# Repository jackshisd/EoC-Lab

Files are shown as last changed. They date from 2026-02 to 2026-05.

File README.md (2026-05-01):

| Supported Targets | ESP32 | ESP32-P4 | ESP32-S3 |
| --- | ----- | --- | --- |

# ESP32-S3 SD + Mic + OV2640 Recorder

__WARNING:__ This project writes audio/video files to the SD card. Back up your data before testing.

Records:
- **Audio**: WAV via I2S mic (ICS-43434), `mic_0001.wav`, `mic_0002.wav`, ...
- **Contact audio**: WAV via ES8388 contact mic board, `CT0001.WAV`, `CT0002.WAV`, ...
- **Video**: MJPEG via OV2640, `VID0001.MJP`, `VID0002.MJP`, ...

Core features:
- SDMMC FAT mount/unmount
- USB MSC to expose the SD card when idle
- SSD1306 I2C OLED status
- Button UI
- BLE scan trigger (advertisements) with timestamped filenames
- Simultaneous standard mic + contact mic recording to separate WAV files
- Boot-time ES8388 codec bring-up so contact recording does not reinitialize the codec on every session

Supports SD (SDSC, SDHC, SDXC) cards and eMMC.

## Quick wiring map (ESP32-S3)

- **SD card (SDMMC):**
  - CLK: GPIO6
  - CMD: GPIO7
  - D0: GPIO5
  - D1: GPIO4
  - D2: GPIO16
  - D3: GPIO15
- **Mic (I2S):**
  - BCLK: GPIO38
  - LRCK/WS: GPIO40
  - DOUT -> ESP DIN: GPIO39
- **OLED (I2C, addr `0x3C`):**
  - SDA: GPIO1
  - SCL: GPIO2
- **Contact mic codec board (ES8388 + MCP6002):**
  - I2C SDA: GPIO1
  - I2C SCL: GPIO2
  - MCLK: GPIO41
  - ASDOUT -> ESP DIN: GPIO42
  - SCLK/BCLK: GPIO43
  - LRCK/WS: GPIO44
- **Button:**
  - GPIO45
- **Camera (OV2640):**
  - SCCB SDA: GPIO18
  - SCCB SCL: GPIO17
  - XCLK: GPIO9 (10 MHz)
  - D0..D7: GPIO47, GPIO48, GPIO14, GPIO21, GPIO12, GPIO13, GPIO10, GPIO11
  - PCLK: GPIO46
  - VSYNC: GPIO3
  - HREF: GPIO8
  - PWDN/RESET: tied in hardware (disabled in software with `-1`)

## Hardware

This project targets ESP32-S3 and uses an SD card breakout or slot, an I2S mic, an SSD1306 OLED, and an OV2640 camera.

Although it is possible to connect an SD card breakout adapter, keep in mind that connections using breakout cables are often unreliable and have poor signal integrity. You may need to use lower clock frequency when working with SD card breakout adapters.

This project doesn't utilize card detect (CD) and write protect (WP) signals from SD card slot.

### Pin assignments for ESP32

On ESP32, SDMMC peripheral is connected to specific GPIO pins using the IO MUX. GPIO pins cannot be customized. Please see the table below for the pin connections.

When using an ESP-WROVER-KIT board, this example runs without any extra modifications required. Only an SD card needs to be inserted into the slot.

ESP32 pin     | SD card pin | Notes
--------------|-------------|------------
GPIO14 (MTMS) | CLK         | 10k pullup in SD mode
GPIO15 (MTDO) | CMD         | 10k pullup in SD mode
GPIO2         | D0          | 10k pullup in SD mode, pull low to go into download mode (see Note about GPIO2 below!)
GPIO4         | D1          | not used in 1-line SD mode; 10k pullup in 4-line SD mode
GPIO12 (MTDI) | D2          | not used in 1-line SD mode; 10k pullup in 4-line SD mode (see Note about GPIO12 below!)
GPIO13 (MTCK) | D3          | not used in 1-line SD mode, but card's D3 pin must have a 10k pullup

### Pin assignments for ESP32-S3 (current project)

On ESP32-S3, SDMMC peripheral is connected to GPIO pins using GPIO matrix. This allows arbitrary GPIOs to be used to connect an SD card. In this example, GPIOs can be configured in two ways:

1. Using menuconfig: Run `idf.py menuconfig` in the project directory and open "SD/MMC Example Configuration" menu.
2. In the source code: See the initialization of `sdmmc_slot_config_t slot_config` structure in the example code.

The table below lists the default pin assignments.

When using an ESP32-S3-USB-OTG board, this example runs without any extra modifications required. Only an SD card needs to be inserted into the slot.

ESP32-S3 pin  | SD card pin | Notes
--------------|-------------|------------
GPIO6         | CLK         | 10k pullup
GPIO7         | CMD         | 10k pullup
GPIO5         | D0          | 10k pullup
GPIO4         | D1          | 10k pullup
GPIO16        | D2          | 10k pullup
GPIO15        | D3          | 10k pullup (required even in 1-line mode)

### I2S mic (ICS-43434)

ESP32-S3 pin  | Mic pin
--------------|---------
GPIO38        | BCLK/SCK
GPIO40        | WS/LRCL
GPIO39        | DOUT/SD
3.3V          | VCC
GND           | GND

SEL/LR on the mic should be tied to 3.3V (right channel), which matches the code.

### OLED (SSD1306, I2C)

ESP32-S3 pin  | OLED pin
--------------|---------
GPIO1         | SDA
GPIO2         | SCL
3.3V          | VCC
GND           | GND

I2C address is `0x3C`.

### Contact mic codec board (ES8388)

ESP32-S3 pin  | Contact mic board pin
--------------|----------------------
GPIO1         | CDATA / I2C SDA
GPIO2         | CCLK / I2C SCL
GPIO41        | MCLK
GPIO42        | ASDOUT / codec data out
GPIO43        | SCLK / BCLK
GPIO44        | LRCK / WS
3.3V          | Codec supply
GND           | GND

Current firmware behavior:

- The ES8388 codec is initialized once at boot.
- If codec init is slow, the OLED shows retry/progress messages during boot.
- Once the OLED shows `codec ok`, normal operation begins.
- Later recordings reuse the initialized codec instead of re-running full codec init every time.

### Camera (OV2640, Waveshare) — read this first

This project uses OV2640 over SCCB (I2C). The camera is sensitive to pin choice and initial frames are often corrupted.

**Current working pin map (ESP32-S3 custom board):**

ESP32-S3 pin | OV2640 pin | Notes
-------------|------------|------
GPIO18       | SCCB SDA   | Camera I2C data
GPIO17       | SCCB SCL   | Camera I2C clock
GPIO9        | XCLK       | External clock (10 MHz)
GPIO47       | D0         | Data bit 0
GPIO48       | D1         | Data bit 1
GPIO14       | D2         | Data bit 2
GPIO21       | D3         | Data bit 3
GPIO12       | D4         | Data bit 4
GPIO13       | D5         | Data bit 5
GPIO10       | D6         | Data bit 6
GPIO11       | D7         | Data bit 7
GPIO46       | PCLK       | Pixel clock
GPIO3        | VSYNC      | Frame sync
GPIO8        | HREF       | Line sync

PWDN and RESET are tied in hardware (PWDN -> GND, RESET -> 3.3V). In software, they are disabled (set to `-1`).

**What was broken and how it was fixed:**

- Camera capture initially failed because of a real solder bridge between `VSYNC` and `PCLK`.
  Fix: remove the bridge; camera now initializes and produces frames.
- OLED instability was partly caused by a pin conflict: OLED `SCL` and the buzzer both used GPIO2.
  Fix: remove all buzzer code so GPIO2 is dedicated to OLED `SCL`.
- Mic audio was silent with one mic connected because the code was reading the wrong I2S slot.
  Fix: switch the mic capture to the right channel and wire the mic `SEL/LR` pin high.
- FATFS without LFN rejects long filenames.
  Fix: keep video filenames 8.3-safe as `VID0001.MJP` and BLE timestamped names as `MMDDHHMM.MJP` / `MMDDHHMM.WAV`.

**Playback note:** `VIDxxxx.MJP` is a raw MJPEG stream (not a container). VLC can play it; for QuickTime, convert to AVI/MP4.

**Current camera behavior:**

- Video recording is capped in software at `10 FPS` to reduce camera/SD load and improve stability.

### BLE trigger and timestamped filenames

The device scans BLE advertisements and uses a UUID-encoded timestamp to name files:

- **Video:** `MMDDHHMM.MJP`
- **Audio:** `MMDDHHMM.WAV`
- **Contact audio:** a contact-mic WAV derived from the same BLE timestamp, with the first timestamp character replaced by `C` to stay 8.3-safe

If no valid BLE timestamp is seen, it falls back to the index names:

- `VID0001.MJP`
- `mic_0001.wav`
- `CT0001.WAV`

**UUID format (128-bit):** `00000000-0000-0000-TT00-YYMMDDHHMMSS`

- Prefix is fixed: all zeroes (`00 00 00 00 00 00 00 00`)
- `TT` = `01` short press, `02` long press
- `YYMMDDHHMMSS` are BCD digits (base-10 nibbles)
- Filenames use `MMDDHHMM` to stay 8.3-safe

**Current BLE scan behavior:**

- BLE trigger scanning is enabled.
- Scanning is passive with duplicate filtering disabled.
- Scan duty cycle was reduced from continuous `10 ms / 10 ms` (~100%) to `5 ms / 80 ms` (~6.25%) to reduce radio and power load while keeping start/stop trigger support during recording.

### Button

ESP32-S3 pin  | Device
--------------|---------
GPIO45        | Button (pull-up input)

### Pin assignments for ESP32-P4

On ESP32-P4, Slot 1 of the SDMMC peripheral is connected to GPIO pins using GPIO matrix. This allows arbitrary GPIOs to be used to connect an SD card. In this example, GPIOs can be configured in two ways:

1. Using menuconfig: Run `idf.py menuconfig` in the project directory and open `SD/MMC Example Configuration` menu.
2. In the source code: See the initialization of `sdmmc_slot_config_t slot_config` structure in the example code.

The table below lists the default pin assignments.

ESP32-P4 pin  | SD card pin | Notes
--------------|-------------|------------
GPIO43        | CLK         | 10k pullup
GPIO44        | CMD         | 10k pullup
GPIO39        | D0          | 10k pullup
GPIO40        | D1          | not used in 1-line SD mode; 10k pullup in 4-line mode
GPIO41        | D2          | not used in 1-line SD mode; 10k pullup in 4-line mode
GPIO42        | D3          | not used in 1-line SD mode, but card's D3 pin must have a 10k pullup

Default dedicated pins on ESP32-P4 are able to connect to an ultra high-speed SD card (UHS-I) which requires 1.8V switching (instead of the regular 3.3V). This means the user has to provide an external LDO power supply to use them, or to enable and configure an internal LDO via `idf.py menuconfig` -> `SD/MMC Example Configuration` -> `SD power supply comes from internal LDO IO`.

When using different GPIO pins this is not required and `SD power supply comes from internal LDO IO` setting can be disabled.

### 4-line and 1-line SD modes

By default, this example uses 4 line SD mode, utilizing 6 pins: CLK, CMD, D0 - D3. It is possible to use 1-line mode (CLK, CMD, D0) by changing "SD/MMC bus width" in the example configuration menu (see `CONFIG_EXAMPLE_SDMMC_BUS_WIDTH_1`).

Note that even if card's D3 line is not connected to the ESP chip, it still has to be pulled up, otherwise the card will go into SPI protocol mode.

### Note about GPIO2 (ESP32 only)

GPIO2 pin is used as a bootstrapping pin, and should be low to enter UART download mode. One way to do this is to connect GPIO0 and GPIO2 using a jumper, and then the auto-reset circuit on most development boards will pull GPIO2 low along with GPIO0, when entering download mode.

- Some boards have pulldown and/or LED on GPIO2. LED is usually ok, but pulldown will interfere with D0 signals and must be removed. Check the schematic of your development board for anything connected to GPIO2.

### Note about GPIO12 (ESP32 only)

GPIO12 is used as a bootstrapping pin to select output voltage of an internal regulator which powers the flash chip (VDD_SDIO). This pin has an internal pulldown so if left unconnected it will read low at reset (selecting default 3.3V operation). When adding a pullup to this pin for SD card operation, consider the following:

- For boards which don't use the internal regulator (VDD_SDIO) to power the flash, GPIO12 can be pulled high.
- For boards which use 1.8V flash chip, GPIO12 needs to be pulled high at reset. This is fully compatible with SD card operation.
- On boards which use the internal regulator and a 3.3V flash chip, GPIO12 must be low at reset. This is incompatible with SD card operation.
    * In most cases, external pullup can be omitted and an internal pullup can be enabled using a `gpio_pullup_en(GPIO_NUM_12);` call. Most SD cards work fine when an internal pullup on GPIO12 line is enabled. Note that if ESP32 experiences a power-on reset while the SD card is sending data, high level on GPIO12 can be latched into the bootstrapping register, and ESP32 will enter a boot loop until external reset with correct GPIO12 level is applied.
    * Another option is to burn the flash voltage selection efuses. This will permanently select 3.3V output voltage for the internal regulator, and GPIO12 will not be used as a bootstrapping pin. Then it is safe to connect a pullup resistor to GPIO12. This option is suggested for production use.

The following command can be used to program flash voltage selection efuses **to 3.3V**:

```sh
    espefuse.py set_flash_voltage 3.3V
```

This command will burn the `XPD_SDIO_TIEH`, `XPD_SDIO_FORCE`, and `XPD_SDIO_REG` efuses. With all three burned to value 1, the internal VDD_SDIO flash voltage regulator is permanently enabled at 3.3V. See the technical reference manual for more details.

`espefuse.py` has a `--do-not-confirm` option if running from an automated flashing script.

See [the document about pullup requirements](https://docs.espressif.com/projects/esp-idf/en/latest/api-reference/peripherals/sd_pullup_requirements.html) for more details about pullup support and compatibility of modules and development boards.

## How to use

### Build and flash

Build the project and flash it to the board, then run monitor tool to view serial output:

```
idf.py -p PORT flash monitor
```

(Replace PORT with serial port name.)

(To exit the serial monitor, type ``Ctrl-]``.)

### Recording flow

1. Long press starts recording. USB MSC is stopped and the SD card is mounted to the app.
2. The normal I2S mic and the ES8388 contact mic are both recorded at the same time into separate WAV files.
3. Video is recorded in parallel if the camera is enabled and initialized.
4. Long press again stops recording, finalizes the WAV header(s), waits for the camera task to stop, and returns the SD card to USB MSC.
5. A later long press repeats the cycle with a new filename set.

### Idle / post-record OLED messages

The OLED status is more specific than a generic `Ready` screen:

- Clean success: `Recorded Xs at` + the standard mic filename
- Standard mic file exists even if the task reported a higher-level failure: `Mic file saved`
- Standard mic saved but contact mic failed: `Mic saved; c fail`
- Startup codec bring-up: retry/progress messages followed by `codec ok`

Short press toggles pause/resume during recording.

### SD card mount warnings

If SD mounting fails or is not ready, the OLED shows a warning:

- `SD init failed`
- `SD mount failed`
- `SD not ready`

When these appear, re-seat the SD card and try again. Also wait for the
`Exposing SD card over USB` log before unplugging or copying files.

See the Getting Started Guide for full steps to configure and use ESP-IDF to build projects.

### USB mass storage

When idle, the SD card is exposed over USB MSC for file access from your computer.
During recording, USB MSC is stopped and the SD card is mounted to the application.
After recording finishes, USB MSC is restarted and the card is visible again on the host.

## Example output

Here is an example console output. In this case a 128MB SDSC card was connected, and `EXAMPLE_FORMAT_IF_MOUNT_FAILED` menuconfig option enabled. Card was unformatted, so the initial mount has failed. Card was then partitioned, formatted, and mounted again.

```
I (336) example: Initializing SD card
I (336) example: Using SDMMC peripheral
I (420) example: Mounting filesystem
I (538) mic: Waiting for long press
I (1840) button: Recording started
I (1841) mic: Recording started
I (9620) mic: Stop requested
I (9622) mic: Captured 7 sec to /sdcard/mic_0001.wav
I (9660) example: Card unmounted
```

## Troubleshooting

### Failure to download the example

```
Connecting........_____....._____....._____....._____....._____....._____....._____

A fatal error occurred: Failed to connect to Espressif device: Invalid head of packet (0x34)
```

Disconnect the SD card D0/MISO line from GPIO2 and try uploading again. Read "Note about GPIO2" above.

### Card fails to initialize with `sdmmc_init_sd_scr: send_scr (1) returned 0x107` error

Check connections between the card and the ESP32. For example, if you have disconnected GPIO2 to work around the flashing issue, connect it back and reset the ESP32 (using a button on the development board, or by pressing Ctrl-T Ctrl-R in IDF Monitor).

### Card fails to initialize with `sdmmc_check_scr: send_scr returned 0xffffffff` error

Connections between the card and the ESP32 are too long for the frequency used. Try using shorter connections, or try reducing the clock speed of SD interface.

### Failure to mount filesystem

```
example: Failed to mount filesystem. If you want the card to be formatted, set the EXAMPLE_FORMAT_IF_MOUNT_FAILED menuconfig option.
```
The example will be able to mount only cards formatted using FAT32 filesystem. If the card is formatted as exFAT or some other filesystem, you have an option to format it in the example code. Enable the `EXAMPLE_FORMAT_IF_MOUNT_FAILED` menuconfig option, then build and flash the example.

### Debug SD connections and pullup strength

> If the initialization of the SD card fails, initially follow the above options. If the issue persists, confirm the connection of pullups to the SD pins. To do this, enable the` Debug sd pin connections and pullup strength` option from menuconfig and rerun the code. This will provide the following result:

```
**** PIN recovery time ****

PIN 14 CLK  10044 cycles
PIN 15 CMD  10034 cycles
PIN  2  D0  10034 cycles
PIN  4  D1  10034 cycles
PIN 12  D2  10034 cycles
PIN 13  D3  10034 cycles

**** PIN recovery time with weak pullup ****

PIN 14 CLK  100 cycles
PIN 15 CMD  100 cycles
PIN  2  D0  100 cycles
PIN  4  D1  100 cycles
PIN 12  D2  100 cycles
PIN 13  D3  100 cycles

**** PIN voltage levels ****

PIN 14 CLK  0.6V
PIN 15 CMD  0.3V
PIN  2  D0  0.8V
PIN  4  D1  0.6V
PIN 12  D2  0.4V
PIN 13  D3  0.8V

**** PIN voltage levels with weak pullup ****

PIN 14 CLK  1.0V
PIN 15 CMD  1.1V
PIN  2  D0  1.0V
PIN  4  D1  1.0V
PIN 12  D2  1.0V
PIN 13  D3  1.2V

**** PIN cross-talk ****

              CLK   CMD    D0    D1    D2    D3
PIN 14 CLK     --   0.2V  0.1V  0.1V  0.1V  0.2V
PIN 15 CMD    0.1V   --   0.1V  0.1V  0.1V  0.1V
PIN  2  D0    0.1V  0.1V   --   0.2V  0.1V  0.1V
PIN  4  D1    0.1V  0.1V  0.3V   --   0.1V  0.1V
PIN 12  D2    0.1V  0.2V  0.2V  0.1V   --   0.1V
PIN 13  D3    0.1V  0.2V  0.1V  0.1V  0.1V   --

**** PIN cross-talk with weak pullup ****

              CLK   CMD    D0    D1    D2    D3
PIN 14 CLK     --   1.0V  1.0V  1.0V  1.0V  1.2V
PIN 15 CMD    0.9V   --   1.0V  1.0V  1.0V  1.2V
PIN  2  D0    0.9V  1.0V   --   1.0V  1.0V  1.2V
PIN  4  D1    0.9V  1.0V  1.2V   --   1.0V  1.2V
PIN 12  D2    0.9V  1.1V  1.2V  0.9V   --   1.2V
PIN 13  D3    0.9V  1.2V  1.1V  0.9V  0.9V   --
I (845) main_task: Returned from app_main()
```

In the absence of connected pullups and having the weak pullups enabled, you can assess the pullup connections by comparing PIN recovery time measured in CPU cycles. To check pullup connections, configure the pin as open drain, set it to low state, and count the cpu cycles consumed before returning to high state. If a pullup is connected, the pin will get back to high state after reasonably small cycle count, typically around 50-300 cycles, depending on pullup strength. If no pullup is connected, the PIN stays low and the measurement times out after 10000 cycles.

It will also provide the voltage levels at the corresponding SD pins. By default, this information is provided for ESP32 chip only, and for other chipsets, verify the availability of ADC pins for the respective GPIO using [this](https://docs.espressif.com/projects/esp-idf/en/latest/esp32/api-reference/peripherals/gpio.html#gpio-summary) and configure ADC mapped pins using menuconfig. Then test the voltage levels accordingly.

You can monitor the voltage levels of individual pins using `PIN voltage levels` and `PIN voltage levels with weak pullup`. However, if one pin being pulled low and experiencing interference with another pin, you can detect it through `PIN cross-talk` and `PIN cross-talk with weak pullup`. In the absence of pullups, voltage levels at each pin should range from 0 to 0.3V. With 10k pullups connected, the voltage will be between 3.1V to 3.3V, contingent on the connection between ADC pins and SD pins, and with weak pullups connected, it can fluctuate between 0.8V to 1.2V, depending on pullup strength.
>>>>>>> 207d2c1 (Initial commit)

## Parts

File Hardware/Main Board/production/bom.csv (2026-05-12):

Designator | Footprint | Quantity | Value | LCSC Part #
1V2, A2V8, BATT1, TP6, TP7, TP9, VIN1 | TestPoint_Pad_1.0x1.0mm | 7 | TestPoint
3V3, GND1, TP3 | PinHeader_1x01_P2.54mm_Vertical | 3 | TestPoint
600Ω@100MHZ1 | 0603 | 1 | FerriteBead
BOOT1, RESET1, USER_INPUT1 | SW_SPST_TL3342 | 3 | SW_Push
BT1 | JST_PH_S2B-PH-K_1x02_P2.00mm_Horizontal | 1 | Battery_Cell
C1, C3, C8 | 0402 | 3 | 0.1uF
C10, C2, C7 | 0402 | 3 | 10uF
C11, C12, C13 | 0805 | 3 | 22uF
C14, C15, C16, C17 | 0603 | 4 | 0.1uF
C18, C19, C20, C21 | 0603 | 4 | 1uF
C4, C5, C6 | 0603 | 3 | 10uF
C9 | 0402 | 1 | 10pF
CAM1 | OV2640 | 1 | OV2640
D1 | PinHeader_1x02_P2.54mm_Vertical | 1 | LED
D2, D3 | 0603 | 2 | LED
D5 | D_SMA | 1 | SS14
F1 | 1206 | 1 | Fuse
J1 | microSD_HC_Molex_104031-0811 | 1 | Micro_SD_Card_Det1
J3 | JST_GH_SM09B-GHS-TB_1x09-1MP_P1.25mm_Horizontal | 1 | Conn_01x09_Socket
J4 | JST_GH_SM06B-GHS-TB_1x06-1MP_P1.25mm_Horizontal | 1 | MIC 1 Connector
J5 | JST_GH_SM06B-GHS-TB_1x06-1MP_P1.25mm_Horizontal | 1 | MIC 2 Connector
J6 | USB_C_Receptacle_HRO_TYPE-C-31-M-12 | 1 | USB_C_Receptacle_USB2.0_16P
J7 | PinHeader_1x04_P2.54mm_Vertical | 1 | OLED
L1 | L_Bourns-SRN4018 | 1 | 1uH
Q1 | SOT-23 | 1 | AO3401A
R1, R12, R13, R14 | 0402 | 4 | 10k
R10, R23, R28, R9 | 0402 | 4 | 22
R11, R17, R26 | 0402 | 3 | 4.7k
R15, R27 | 0402 | 2 | 0
R16 | 0402 | 1 | 560k
R18, R24 | 0402 | 2 | 100k
R19 | 0402 | 1 | 1M
R2, R3, R4, R5, R6, R7 | 0402 | 6 | 47k
R21, R22 | 0402 | 2 | 5.1k
SW1 | PinHeader_1x03_P2.54mm_Vertical | 1 | SW_SPST
U1 | ESP32-S3-WROOM-2 | 1 | ESP32-S3-WROOM-2
U2 | Texas_S-PWSON-N10_ThermalVias | 1 | TPS63060
U3 | SOIC-8-1EP_3.9x4.9mm_P1.27mm_EP2.41x3.3mm_ThermalVias | 1 | TP4056-42-ESOP8
U4 | SOT-23-5 | 1 | TLV75528PDBV
U6 | SOT-23-5 | 1 | AP2112K-1.2

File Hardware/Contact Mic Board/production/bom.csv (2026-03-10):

Designator | Footprint | Quantity | Value | LCSC Part #
C1, C16, C18, C19, C3, C5, C6 | 0402 | 7 | 0.1uF
C10, C13, C8, C9 | 0402 | 4 | 1uF
C11, C12 | 0402 | 2 | 470nF
C14, C15, C17, C2, C20, C4, C7 | 0402 | 7 | 10uF
FB1 | 0603 | 1 | FerriteBead_Small
J1 | JST_GH_SM09B-GHS-TB_1x09-1MP_P1.25mm_Horizontal | 1 | Conn_01x09_Pin
R1, R2 | 0402 | 2 | 47k
R10, R9 | 0402 | 2 | 1M
R11, R12, R13, R14 | 0402 | 4 | 33
R3, R4 | 0402 | 2 | 10M
R5, R6 | 0805 | 2 | 100k
R7, R8 | 0402 | 2 | 10K
U1 | QFN-28-1EP_4x4mm_P0.45mm_EP2.6x2.6mm | 1 | ES8388
U2 | DFN-8-1EP_3x2mm_P0.5mm_EP1.75x1.45mm | 1 | MCP6002-xMC

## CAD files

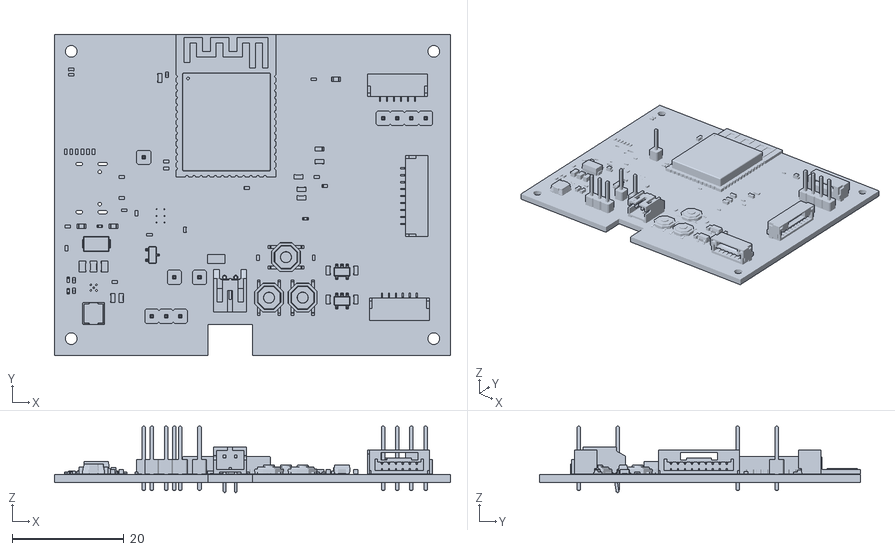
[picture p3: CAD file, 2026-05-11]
Hardware/Main Board/Main Board.stl
71.0 x 57.5 x 11.9

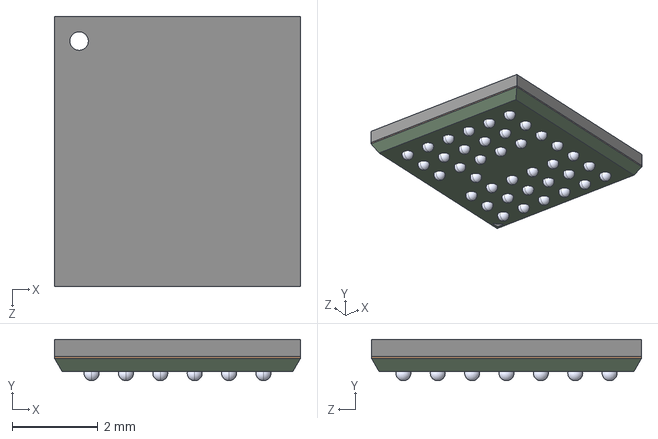
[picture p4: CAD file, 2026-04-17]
Hardware/Main Board/OV2640/OV2640.step
5.72 x 0.965 x 6.29 mm

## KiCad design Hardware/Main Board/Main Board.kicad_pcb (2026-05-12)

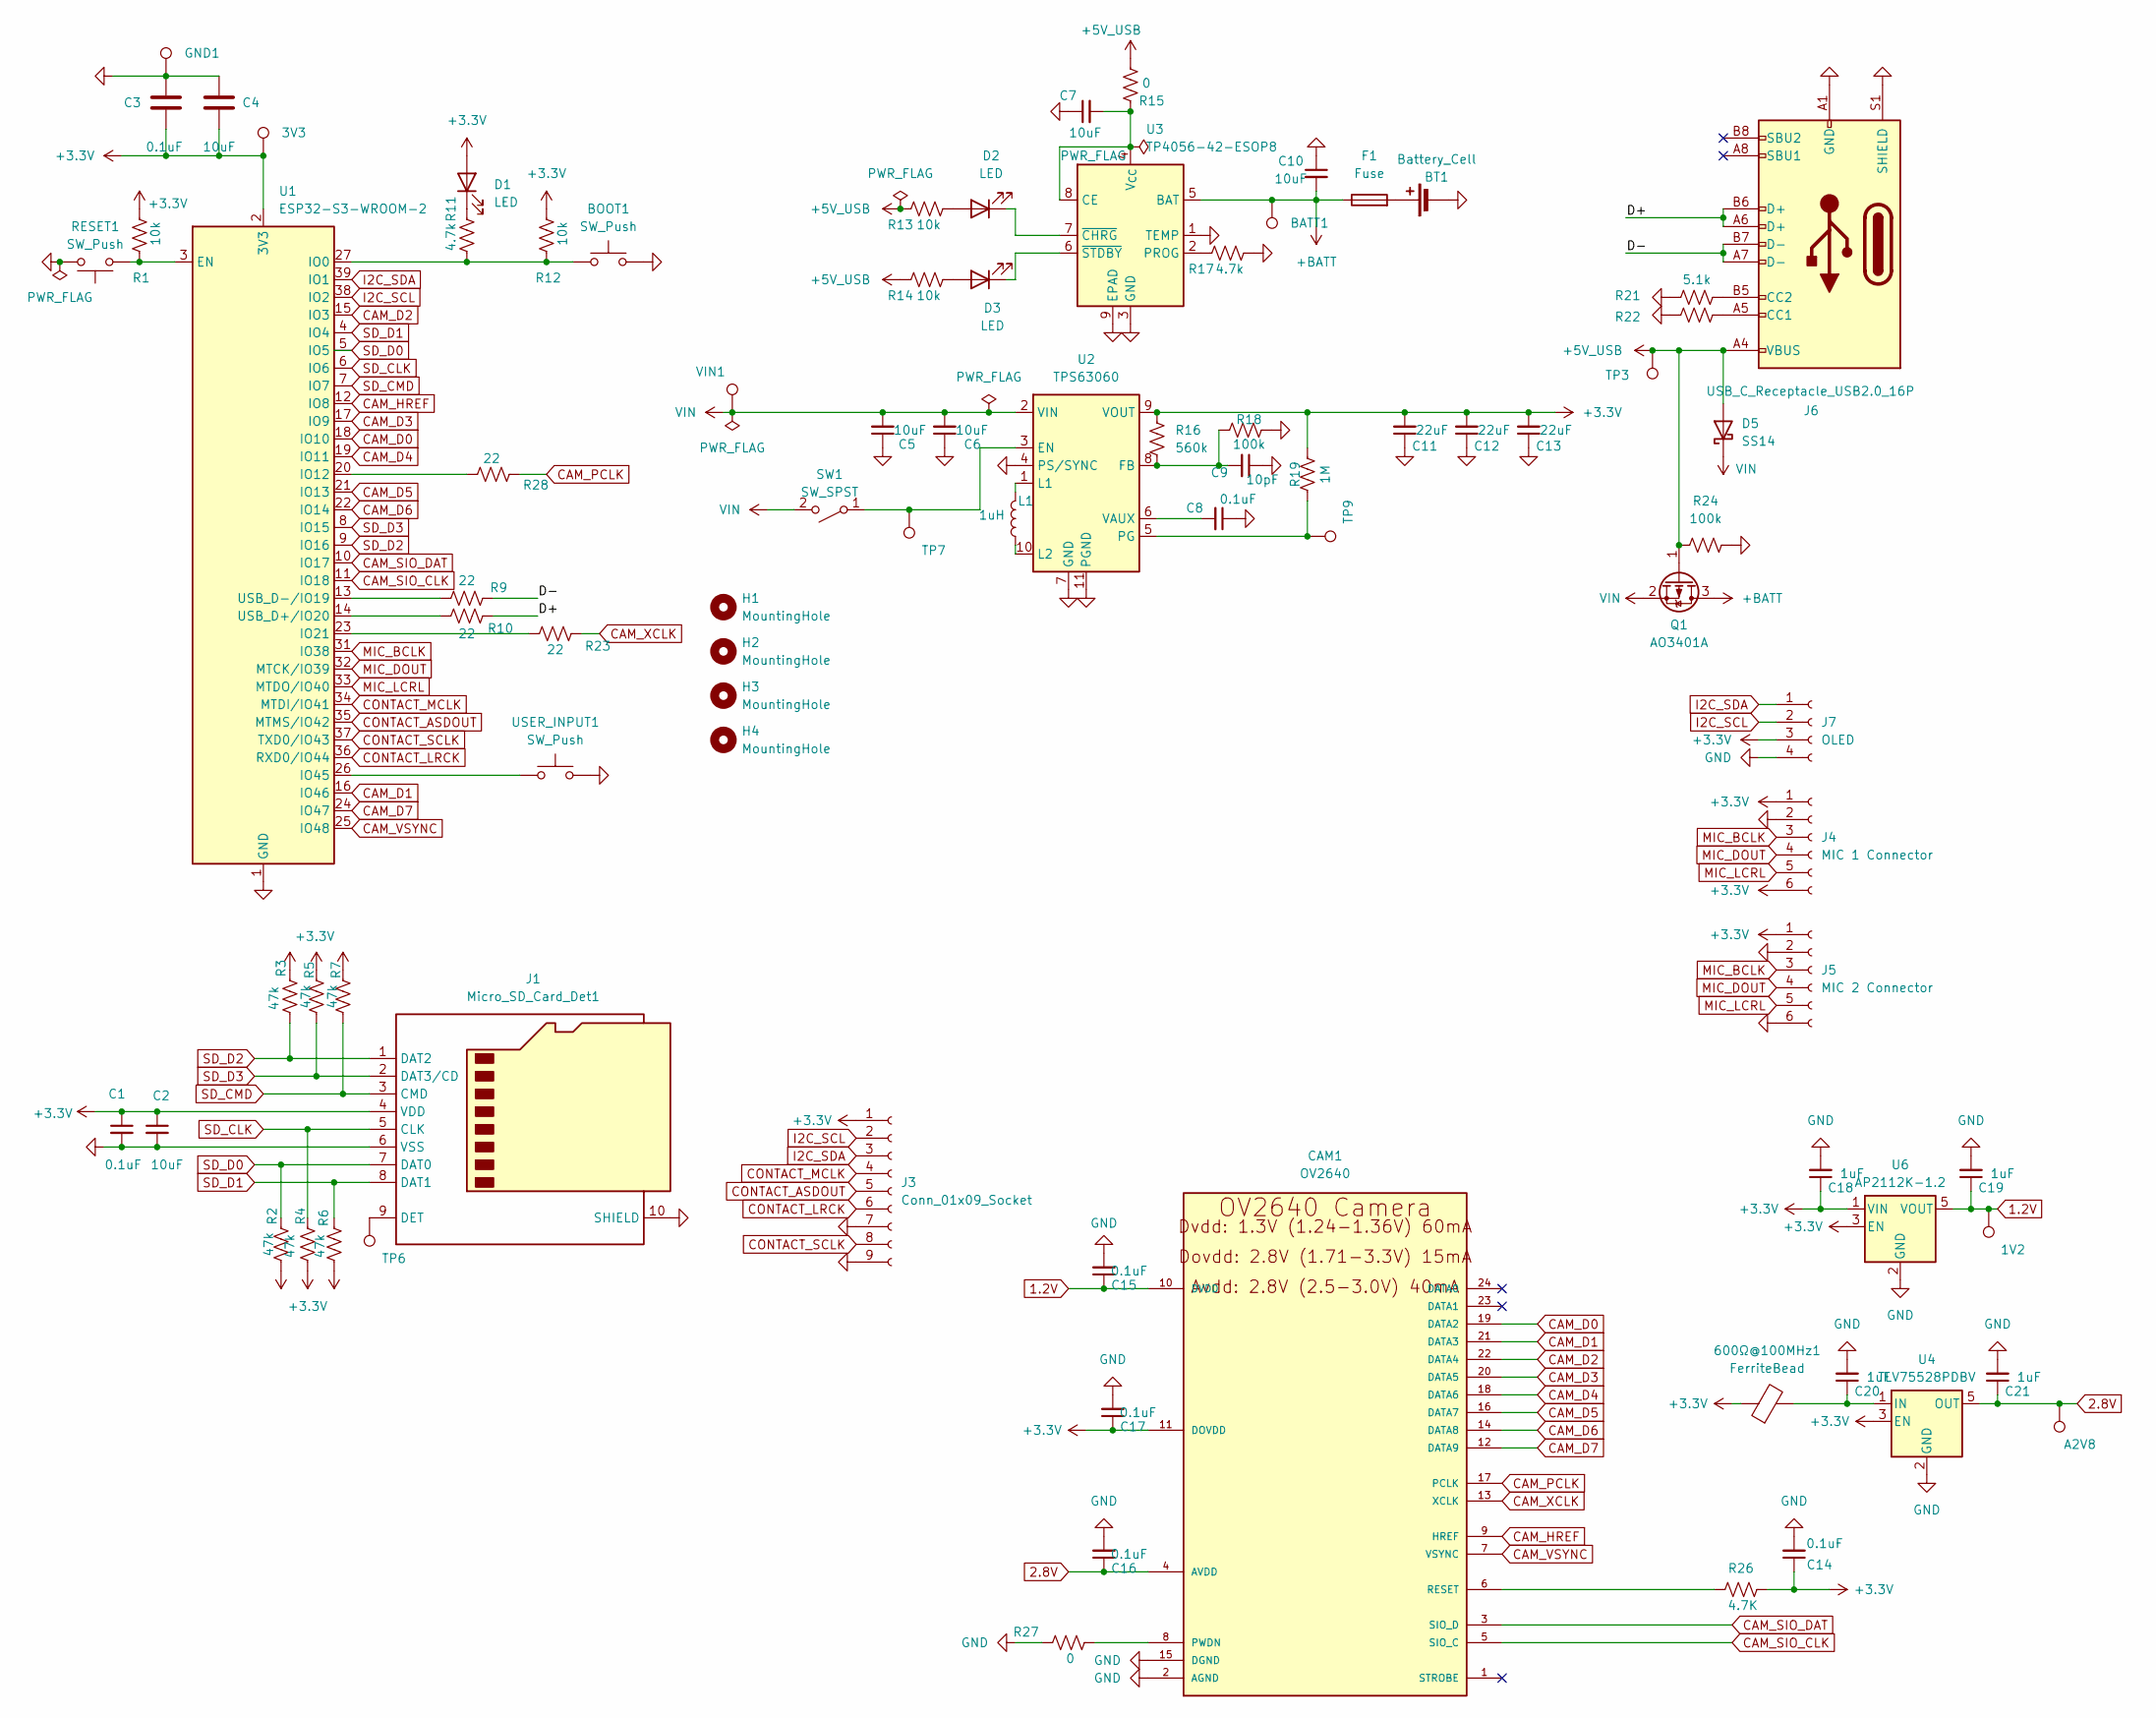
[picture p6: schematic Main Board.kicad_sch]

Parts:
1V2: TestPoint; TestPoint_Pad_1.0x1.0mm
3V3: TestPoint; PinHeader_1x01_P2.54mm_Vertical
600Ω@100MHz1: FerriteBead; R_0603_1608Metric
A2V8: TestPoint; TestPoint_Pad_1.0x1.0mm
BATT1: TestPoint; TestPoint_Pad_1.0x1.0mm
BOOT1: SW_Push; SW_SPST_TL3342
BT1: Battery_Cell; JST_PH_S2B-PH-K_1x02_P2.00mm_Horizontal
C1, C3, C8: 0.1uF; C_0402_1005Metric
C2, C7, C10: 10uF; C_0402_1005Metric
C4, C5, C6: 10uF; C_0603_1608Metric
C9: 10pF; C_0402_1005Metric
C11, C12, C13: 22uF; C_0805_2012Metric
C14, C15, C16, C17: 0.1uF; C_0603_1608Metric
C18, C19, C20, C21: 1uF; C_0603_1608Metric
CAM1: OV2640
D1: LED; PinHeader_1x02_P2.54mm_Vertical
D2, D3: LED; LED_0603_1608Metric
D5: SS14; D_SMA
F1: Fuse; Fuse_1206_3216Metric
GND1: TestPoint; PinHeader_1x01_P2.54mm_Vertical
H1, H2, H3, H4: MountingHole; MountingHole_2.1mm
J1: Micro_SD_Card_Det1; microSD_HC_Molex_104031-0811
J3: Conn_01x09_Socket; JST_GH_SM09B-GHS-TB_1x09-1MP_P1.25mm_Horizontal
J4: MIC 1 Connector; JST_GH_SM06B-GHS-TB_1x06-1MP_P1.25mm_Horizontal
J5: MIC 2 Connector; JST_GH_SM06B-GHS-TB_1x06-1MP_P1.25mm_Horizontal
J6: USB_C_Receptacle_USB2.0_16P; USB_C_Receptacle_HRO_TYPE-C-31-M-12
J7: OLED; PinHeader_1x04_P2.54mm_Vertical
L1: 1uH; L_Bourns-SRN4018
Q1: AO3401A; SOT-23
R1, R12, R13, R14: 10k; R_0402_1005Metric
R2, R3, R4, R5, R6, R7: 47k; R_0402_1005Metric
R9, R10, R23, R28: 22; R_0402_1005Metric
R11, R17: 4.7k; R_0402_1005Metric
R15, R27: 0; R_0402_1005Metric
R16: 560k; R_0402_1005Metric
R18, R24: 100k; R_0402_1005Metric
R19: 1M; R_0402_1005Metric
R21, R22: 5.1k; R_0402_1005Metric
R26: 4.7K; R_0402_1005Metric
RESET1: SW_Push; SW_SPST_TL3342
SW1: SW_SPST; PinHeader_1x03_P2.54mm_Vertical
TP3: TestPoint; PinHeader_1x01_P2.54mm_Vertical
TP6, TP7, TP9: TestPoint; TestPoint_Pad_1.0x1.0mm
U1: ESP32-S3-WROOM-2
U2: TPS63060; Texas_S-PWSON-N10_ThermalVias
U3: TP4056-42-ESOP8; SOIC-8-1EP_3.9x4.9mm_P1.27mm_EP2.41x3.3mm_ThermalVias
U4: TLV75528PDBV; SOT-23-5
U6: AP2112K-1.2; SOT-23-5
USER_INPUT1: SW_Push; SW_SPST_TL3342
VIN1: TestPoint; TestPoint_Pad_1.0x1.0mm

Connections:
1.2V: 1V2.1, C15.1, C19.1, CAM1.10 (DVDD), U6.5 (VOUT)
2.8V: A2V8.1, C16.1, C21.1, CAM1.4 (AVDD), U4.5 (OUT)
+3.3V: 3V3.1, 600Ω@100MHz1.1, C1.1, C2.1, C3.2, C4.1, C11.2, C12.2, C13.2, C14.1, C17.1, C18.1, CAM1.11 (DOVDD), D1.2 (A), J1.4 (VDD), J3.1, J4.1, J4.6, J5.1, J7.3, R1.1, R2.1, R3.2, R4.1, R5.2, R6.1, R7.2, R12.1, R16.2, R19.2, R26.1, U1.2 (3V3), U2.9 (VOUT), U4.3 (EN), U6.1 (VIN), U6.3 (EN)
+5V_USB: D5.2 (A), J6.A4 (VBUS), J6.A9 (VBUS), J6.B4 (VBUS), J6.B9 (VBUS), Q1.1 (G), R13.2, R14.2, R15.1, R24.1, TP3.1
+BATT: BATT1.1, C10.2, F1.1, Q1.3 (D), U3.5 (BAT)
/D+: J6.A6 (D+), J6.B6 (D+), R10.1
/D-: J6.A7 (D-), J6.B7 (D-), R9.1
CAM_D0: CAM1.19 (DATA2), U1.18 (IO10)
CAM_D1: CAM1.21 (DATA3), U1.16 (IO46)
CAM_D2: CAM1.22 (DATA4), U1.15 (IO3)
CAM_D3: CAM1.20 (DATA5), U1.17 (IO9)
CAM_D4: CAM1.18 (DATA6), U1.19 (IO11)
CAM_D5: CAM1.16 (DATA7), U1.21 (IO13)
CAM_D6: CAM1.14 (DATA8), U1.22 (IO14)
CAM_D7: CAM1.12 (DATA9), U1.24 (IO47)
CAM_HREF: CAM1.9 (HREF), U1.12 (IO8)
CAM_PCLK: CAM1.17 (PCLK), R28.2
CAM_SIO_CLK: CAM1.5 (SIO_C), U1.11 (IO18)
CAM_SIO_DAT: CAM1.3 (SIO_D), U1.10 (IO17)
CAM_VSYNC: CAM1.7 (VSYNC), U1.25 (IO48)
CAM_XCLK: CAM1.13 (XCLK), R23.2
CONTACT_ASDOUT: J3.5, U1.35 (MTMS/IO42)
CONTACT_LRCK: J3.6, U1.36 (RXD0/IO44)
CONTACT_MCLK: J3.4, U1.34 (MTDI/IO41)
CONTACT_SCLK: J3.8, U1.37 (TXD0/IO43)
GND: BOOT1.2, BT1.2 (-), C1.2, C2.2, C3.1, C4.2, C5.1, C6.1, C7.1, C8.1, C9.1, C10.1, C11.1, C12.1, C13.1, C14.2, C15.2, C16.2, C17.2, C18.2, C19.2, C20.2, C21.2, CAM1.2 (AGND), CAM1.15 (DGND), CAM1.MT1 (DGND), CAM1.MT2 (DGND), GND1.1, J1.6 (VSS), J1.10 (SHIELD), J3.7, J3.9, J4.2, J5.2, J5.6, J6.A1 (GND), J6.A12 (GND), J6.B1 (GND), J6.B12 (GND), J6.S1 (SHIELD), J7.4, R17.1, R18.1, R21.2, R22.2, R24.2, R27.2, RESET1.2, U1.1 (GND), U1.40 (GND), U1.41 (GND), U2.4 (PS/SYNC), U2.7 (GND), U2.11 (PGND), U3.1 (TEMP), U3.3 (GND), U3.9 (EPAD), U4.2 (GND), U6.2 (GND), USER_INPUT1.2
I2C_SCL: J3.2, J7.2, U1.38 (IO2)
I2C_SDA: J3.3, J7.1, U1.39 (IO1)
MIC_BCLK: J4.3, J5.3, U1.31 (IO38)
MIC_DOUT: J4.4, J5.4, U1.32 (MTCK/IO39)
MIC_LCRL: J4.5, J5.5, U1.33 (MTDO/IO40)
unnamed: BT1.1 (+), F1.2
unnamed: CAM1.8 (PWDN), R27.1
unnamed: CAM1.6 (RESET), R26.2
unnamed: D1.1 (K), R11.2
unnamed: D2.2 (A), R13.1
unnamed: D2.1 (K), U3.7 (~CHRG)
unnamed: D3.2 (A), R14.1
unnamed: D3.1 (K), U3.6 (~STDBY)
unnamed: J1.9 (DET), TP6.1
unnamed: J6.A5 (CC1), R22.1
unnamed: J6.B5 (CC2), R21.1
unnamed: SW1.1 (A), TP7.1, U2.3 (EN)
unnamed: R1.2, RESET1.1, U1.3 (EN)
unnamed: BOOT1.1, R11.1, R12.2, U1.27 (IO0)
unnamed: R28.1, U1.20 (IO12)
unnamed: R23.1, U1.23 (IO21)
unnamed: U1.26 (IO45), USER_INPUT1.1
unnamed: R10.2, U1.14 (USB_D+/IO20)
unnamed: R9.2, U1.13 (USB_D-/IO19)
unnamed: C9.2, R16.1, R18.2, U2.8 (FB)
unnamed: L1.2, U2.1 (L1)
unnamed: L1.1, U2.10 (L2)
unnamed: R19.1, TP9.1, U2.5 (PG)
unnamed: C8.2, U2.6 (VAUX)
unnamed: C7.2, R15.2, U3.4 (V_{CC}), U3.8 (CE)
unnamed: R17.2, U3.2 (PROG)
unnamed: 600Ω@100MHz1.2, C20.1, U4.1 (IN)
SD_CLK: J1.5 (CLK), R4.2, U1.6 (IO6)
SD_CMD: J1.3 (CMD), R7.1, U1.7 (IO7)
SD_D0: J1.7 (DAT0), R2.2, U1.5 (IO5)
SD_D1: J1.8 (DAT1), R6.2, U1.4 (IO4)
SD_D2: J1.1 (DAT2), R3.1, U1.9 (IO16)
SD_D3: J1.2 (DAT3/CD), R5.1, U1.8 (IO15)
VIN: C5.2, C6.2, D5.1 (K), Q1.2 (S), SW1.2 (B), U2.2 (VIN), VIN1.1

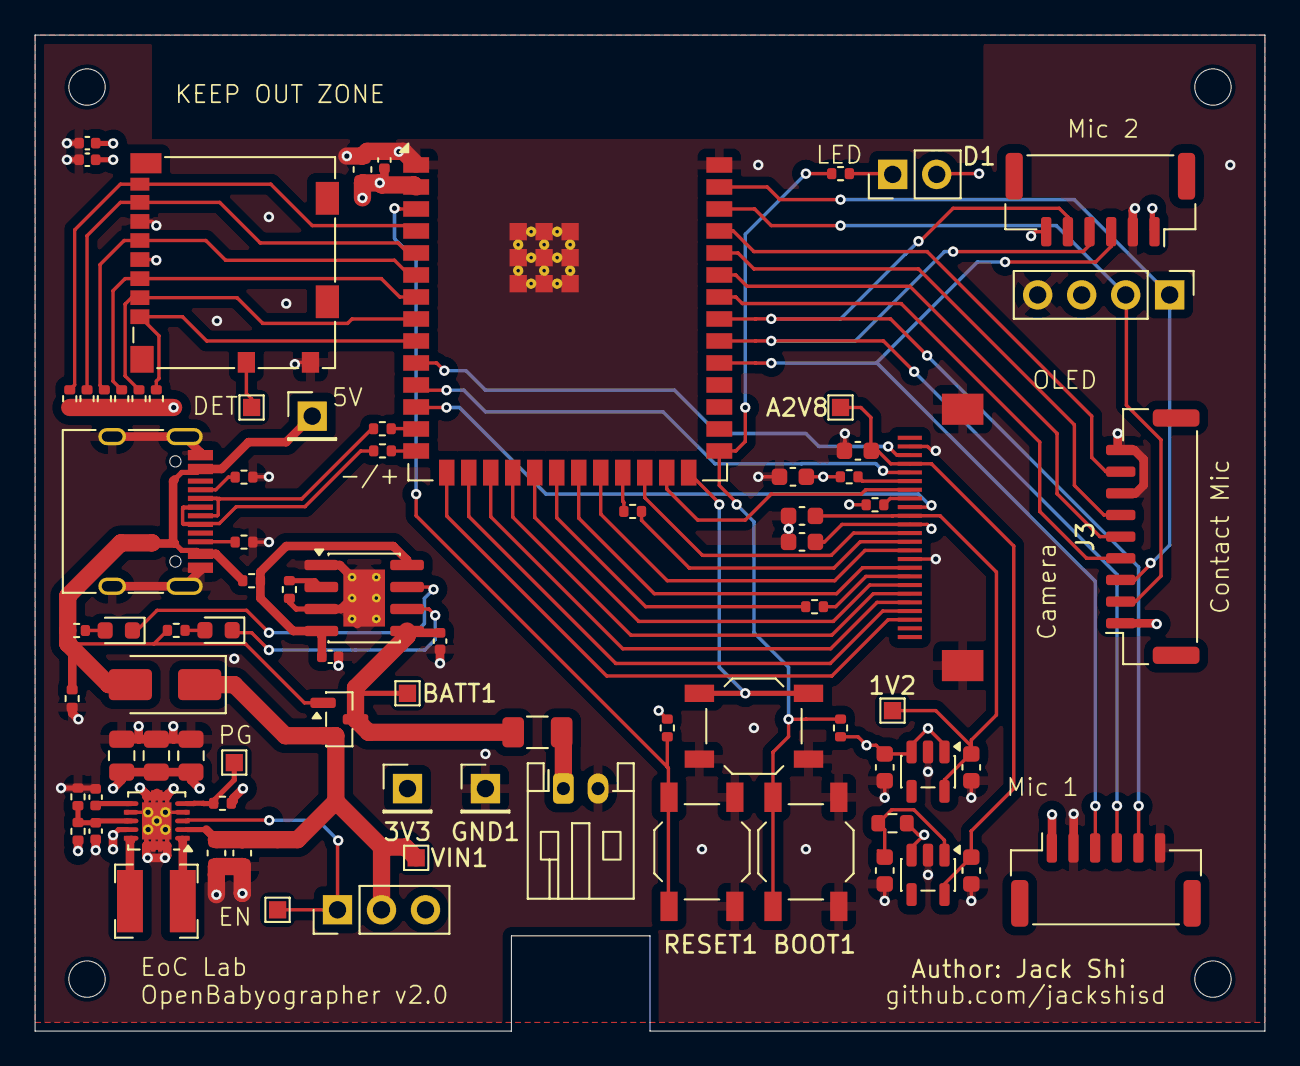
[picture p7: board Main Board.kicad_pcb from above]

Board: 4 copper layers, 71.0 x 57.5 mm, 85 parts (0 on the bottom side), 65 nets.

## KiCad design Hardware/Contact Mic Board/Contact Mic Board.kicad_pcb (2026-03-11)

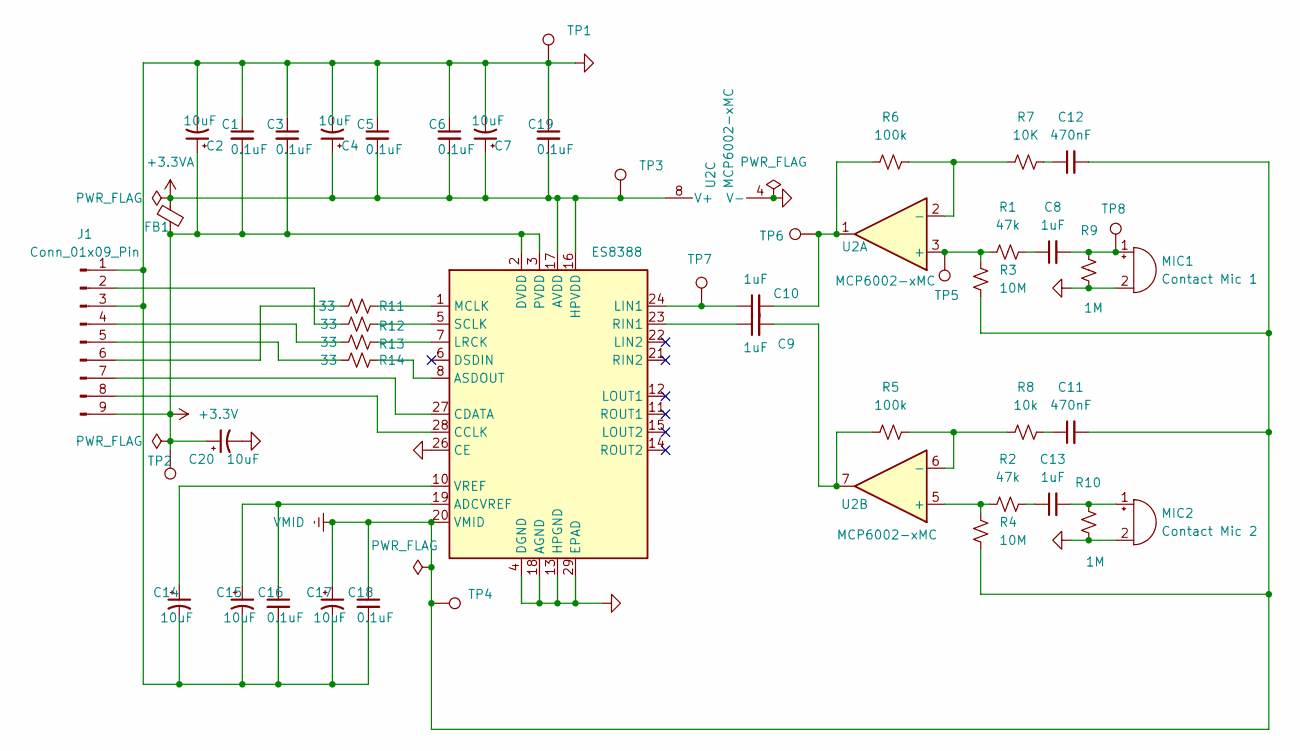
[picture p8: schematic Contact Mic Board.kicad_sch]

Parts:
C1, C3, C5, C6, C16, C18, C19: 0.1uF; C_0402_1005Metric
C2, C4, C7, C14, C15, C17, C20: 10uF; C_0402_1005Metric
C8, C9, C10, C13: 1uF; C_0402_1005Metric
C11, C12: 470nF; C_0402_1005Metric
FB1: FerriteBead_Small; C_0603_1608Metric
J1: Conn_01x09_Pin; JST_GH_SM09B-GHS-TB_1x09-1MP_P1.25mm_Horizontal
MIC1: Contact Mic 1; PinHeader_1x02_P2.54mm_Vertical
MIC2: Contact Mic 2; PinHeader_1x02_P2.54mm_Vertical
R1, R2: 47k; C_0402_1005Metric
R3, R4: 10M; C_0402_1005Metric
R5, R6: 100k; D_0805_2012Metric_Pad1.15x1.40mm_HandSolder
R7: 10K; C_0402_1005Metric
R8: 10k; C_0402_1005Metric
R9, R10: 1M; C_0402_1005Metric
R11, R12, R13, R14: 33; C_0402_1005Metric
TP1, TP2, TP3, TP4, TP5, TP6, TP7, TP8: TestPoint; TestPoint_Pad_1.0x1.0mm
U1: ES8388; QFN-28-1EP_4x4mm_P0.45mm_EP2.6x2.6mm
U2: MCP6002-xMC; DFN-8-1EP_3x2mm_P0.5mm_EP1.75x1.45mm

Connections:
+3.3V: C1.2, C2.1, C3.2, C20.1, FB1.2, J1.9, TP2.1, U1.2 (DVDD), U1.3 (PVDD)
+3.3VA: C4.1, C5.2, C6.2, C7.1, C19.2, FB1.1, TP3.1, U1.16 (HPVDD), U1.17 (AVDD), U2.8 (V+)
GND: C1.1, C2.2, C3.1, C4.2, C5.1, C6.1, C7.2, C14.2, C15.2, C16.2, C17.2, C18.2, C19.1, C20.2, J1.1, J1.3, MIC1.2 (-), MIC2.2 (-), R9.2, R10.2, TP1.1, U1.4 (DGND), U1.13 (HPGND), U1.18 (AGND), U1.26 (CE), U1.29 (EPAD), U2.4 (V-), U2.9 (V-)
unnamed: C8.1, R1.2
unnamed: C9.2, R5.2, U2.7
unnamed: C10.2, R6.1, TP6.1, U2.1
unnamed: C11.1, R8.2
unnamed: C12.1, R7.2
unnamed: C13.1, R2.2
unnamed: J1.2, R12.1
unnamed: J1.4, R13.1
unnamed: J1.5, R14.1
unnamed: J1.6, R11.1
unnamed: J1.7, U1.27 (CDATA)
unnamed: J1.8, U1.28 (CCLK)
unnamed: C8.2, MIC1.1 (+), R9.1, TP8.1
unnamed: C13.2, MIC2.1 (+), R10.1
unnamed: C15.1, C16.1, U1.19 (ADCVREF)
unnamed: R14.2, U1.8 (ASDOUT)
unnamed: C10.1, TP7.1, U1.24 (LIN1)
unnamed: R13.2, U1.7 (LRCK)
unnamed: R11.2, U1.1 (MCLK)
unnamed: C9.1, U1.23 (RIN1)
unnamed: R12.2, U1.5 (SCLK)
unnamed: C14.1, U1.10 (VREF)
unnamed: R1.1, R3.1, TP5.1, U2.3 (+)
unnamed: R6.2, R7.1, U2.2 (-)
unnamed: R2.1, R4.1, U2.5 (+)
unnamed: R5.1, R8.1, U2.6 (-)
VMID: C11.2, C12.2, C17.1, C18.1, R3.2, R4.2, TP4.1, U1.20 (VMID)

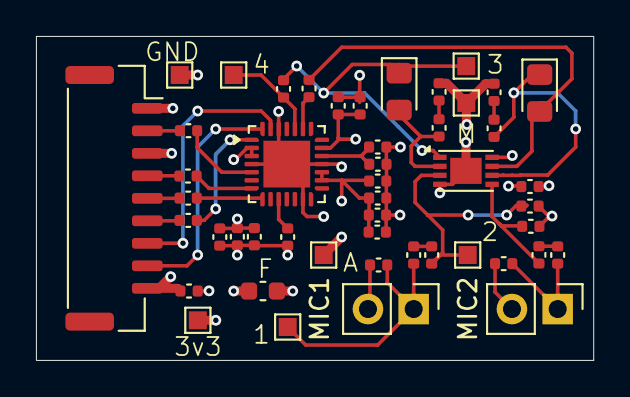
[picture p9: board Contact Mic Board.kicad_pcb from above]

Board: 4 copper layers, 31.0 x 18.0 mm, 48 parts (0 on the bottom side), 30 nets.

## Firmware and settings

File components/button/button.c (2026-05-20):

#include "button.h"

#include <stdio.h>
#include <stdint.h>
#include <stdarg.h>
#include <unistd.h>

#include "driver/gpio.h"
#include "freertos/FreeRTOS.h"
#include "freertos/task.h"
#include "esp_err.h"
#include "esp_log.h"
#include "oled_ssd1306.h"

#define BUTTON_GPIO GPIO_NUM_45
#define DEBOUNCE_MS 30
#define LONG_PRESS_MS 500

static const char *TAG = "button";

static volatile bool s_paused = false;
static volatile bool s_recording = false;
static volatile TickType_t s_record_start_tick = 0;
static volatile uint32_t s_record_elapsed_offset_seconds = 0;
static volatile uint32_t s_record_last_elapsed_seconds = 0;
static char s_status_line[64] = "Ready";
static TickType_t s_oled_next_retry_tick = 0;
static uint8_t s_oled_fail_count = 0;
static char s_oled_last_text[64];

static void s_append_event_log(const char *fmt, ...)
{
    FILE *f = fopen("/sdcard/rec_event.txt", "a");
    if (f == NULL) {
        return;
    }
    va_list args;
    va_start(args, fmt);
    vfprintf(f, fmt, args);
    va_end(args);
    fputc('\n', f);
    fflush(f);
    fsync(fileno(f));
    fclose(f);
}

static void s_log_oled_error_to_sd(esp_err_t err)
{
    FILE *f = fopen("/sdcard/oled_err.txt", "a");
    if (f == NULL) {
        return;
    }
    fprintf(f, "oled write failed: %s (%d)\n", esp_err_to_name(err), (int)err);
    fflush(f);
    fsync(fileno(f));
    fclose(f);
}

// Logs button state changes to the console.
static void s_log_info(const char *text)
{
    ESP_LOGI(TAG, "%s", text);
}

static void s_set_status_line(const char *line1, const char *line2)
{
    if (line1 == NULL) {
        line1 = "";
    }
    if (line2 == NULL) {
        line2 = "";
    }
    snprintf(s_status_line, sizeof(s_status_line), "%s\n%s", line1, line2);
}

static void s_handle_short_press(void)
{
    if (s_recording) {
        s_paused = !s_paused;
        s_log_info(s_paused ? "Paused" : "Recording");
        s_append_event_log("button short press -> %s", s_paused ? "paused" : "resumed");
    }
}

static void s_handle_long_press_internal(const char *reason)
{
    if (s_recording) {
        s_record_last_elapsed_seconds = button_get_record_elapsed_seconds();
        s_recording = false;
        s_paused = false;
        s_set_status_line("Saving...", reason != NULL ? reason : "stop requested");
        s_log_info("Recording stopped");
        s_append_event_log("%s -> stop", reason != NULL ? reason : "button long press");
    } else {
        s_recording = true;
        s_paused = false;
        s_record_start_tick = xTaskGetTickCount();
        s_record_elapsed_offset_seconds = 0;
        s_record_last_elapsed_seconds = 0;
        s_log_info("Recording started");
        s_append_event_log("%s -> start", reason != NULL ? reason : "button long press");
    }
}

// Updates the OLED with timer/status once per second.
static void s_oled_task(void *arg)
{
    (void)arg;
    char buffer[64];
    while (true) {
        if (s_oled_next_retry_tick != 0 && xTaskGetTickCount() < s_oled_next_retry_tick) {
            vTaskDelay(pdMS_TO_TICKS(200));
            continue;
        }
        esp_err_t ret;
        if (s_recording) {
            uint32_t elapsed_seconds = button_get_record_elapsed_seconds();
            uint32_t hours = elapsed_seconds / 3600;
            uint32_t minutes = (elapsed_seconds % 3600) / 60;
            uint32_t seconds = elapsed_seconds % 60;
            const char *line2 = s_paused ? "Paused" : "Recording";
            snprintf(buffer, sizeof(buffer), "%02lu:%02lu:%02lu\n%s",
                     (unsigned long)hours,
                     (unsigned long)minutes,
                     (unsigned long)seconds,
                     line2);
            if (strcmp(buffer, s_oled_last_text) == 0) {
                ret = ESP_OK;
            } else {
                ret = oled_ssd1306_display_text(buffer);
                if (ret == ESP_OK) {
                    snprintf(s_oled_last_text, sizeof(s_oled_last_text), "%s", buffer);
                }
            }
        } else {
            if (strcmp(s_status_line, s_oled_last_text) == 0) {
                ret = ESP_OK;
            } else {
                ret = oled_ssd1306_display_text(s_status_line);
                if (ret == ESP_OK) {
                    snprintf(s_oled_last_text, sizeof(s_oled_last_text), "%s", s_status_line);
                }
            }
        }
        if (ret != ESP_OK) {
            s_log_oled_error_to_sd(ret);
            s_oled_fail_count++;
            if (s_oled_fail_count >= 3) {
                s_oled_next_retry_tick = xTaskGetTickCount() + pdMS_TO_TICKS(5000);
                s_oled_fail_count = 0;
            }
        } else {
            s_oled_fail_count = 0;
            s_oled_next_retry_tick = 0;
        }
        vTaskDelay(pdMS_TO_TICKS(1000));
    }
}

// Handles debounced button presses and toggles recording state.
static void s_button_task(void *arg)
{
    (void)arg;
    bool last_level = true;
    TickType_t press_tick = 0;

    while (true) {
        bool level = gpio_get_level(BUTTON_GPIO);
        if (level != last_level) {
            vTaskDelay(pdMS_TO_TICKS(DEBOUNCE_MS));
            level = gpio_get_level(BUTTON_GPIO);
            if (level != last_level) {
                last_level = level;
                if (!level) {
                    press_tick = xTaskGetTickCount();
                } else {
                    TickType_t held = xTaskGetTickCount() - press_tick;
                    if (held >= pdMS_TO_TICKS(LONG_PRESS_MS)) {
                        s_handle_long_press_internal("button stop");
                    } else {
                        s_handle_short_press();
                    }
                }
            }
        }
        vTaskDelay(pdMS_TO_TICKS(10));
    }
}

// Initializes GPIO and background tasks.
void button_init(void)
{
    gpio_config_t cfg = {
        .pin_bit_mask = 1ULL << BUTTON_GPIO,
        .mode = GPIO_MODE_INPUT,
        .pull_up_en = GPIO_PULLUP_ENABLE,
        .pull_down_en = GPIO_PULLDOWN_DISABLE,
        .intr_type = GPIO_INTR_DISABLE,
    };
    gpio_config(&cfg);

    xTaskCreate(s_button_task, "button_task", 4096, NULL, 10, NULL);
    xTaskCreate(s_oled_task, "oled_task", 4096, NULL, 5, NULL);
}

// Sets the idle OLED display lines shown when not recording.
void button_set_idle_display(const char *line1, const char *line2)
{
    s_set_status_line(line1, line2);
}

void button_force_idle(void)
{
    if (s_recording) {
        s_record_last_elapsed_seconds = button_get_record_elapsed_seconds();
    }
    s_recording = false;
    s_paused = false;
    s_record_start_tick = 0;
    s_record_elapsed_offset_seconds = 0;
    s_log_info("Recording forced idle");
    s_append_event_log("button force idle");
}

// Returns whether recording is currently paused.
bool button_is_paused(void)
{
    return s_paused;
}

// Returns whether recording is currently active.
bool button_is_recording(void)
{
    return s_recording;
}
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

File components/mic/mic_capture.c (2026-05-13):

#include "mic_capture.h"

#include <stdio.h>
#include <stdlib.h>
#include <string.h>
#include <ctype.h>
#include <stdint.h>
#include <errno.h>
#include <unistd.h>
#include <stdarg.h>

#include "esp_log.h"
#include "button.h"
#include "driver/i2c.h"
#include "driver/i2s_std.h"
#include "freertos/FreeRTOS.h"
#include "freertos/task.h"
#include "i2c_bus.h"
#include "oled_ssd1306.h"

#define I2S_SAMPLE_RATE_HZ 16000 // Sample rate
#define I2S_BCLK_IO        38 // Bit clock
#define I2S_WS_IO          40 // Also known as LRCK
#define I2S_DIN_IO         39 // Microphone data input
#define MIC_GAIN_MULT      2  // Microphone gain multiplier
#define MIC_CHANNELS       2  // Stereo capture (left + right)
#define MIC_AUTOSAVE_INTERVAL_MS 10000
#define CONTACT_AUTOSAVE_OFFSET_MS 5000

#define CONTACT_CODEC_I2C_PORT I2C_NUM_1
#define CONTACT_CODEC_I2C_SDA  1
#define CONTACT_CODEC_I2C_SCL  2
#define CONTACT_CODEC_I2C_HZ   100000
#define CONTACT_ES8388_ADDR0   0x10
#define CONTACT_ES8388_ADDR1   0x11
#define CONTACT_I2S_PORT       I2S_NUM_1
#define CONTACT_I2S_MCLK_IO    41
#define CONTACT_I2S_DIN_IO     42
#define CONTACT_I2S_BCLK_IO    43
#define CONTACT_I2S_WS_IO      44
#define CONTACT_BITS_PER_SAMPLE 16
#define CONTACT_MIC_CHANNELS   1
#define CONTACT_CODEC_BOOT_DELAY_MS 500

static const char *TAG = "mic";

typedef struct {
    char path[128];
    int seconds;
} mic_capture_args_t;

static TaskHandle_t s_mic_task = NULL;
static volatile bool s_mic_running = false;
static volatile int s_mic_last_seconds = 0;
static volatile esp_err_t s_mic_last_result = ESP_OK;
static volatile TickType_t s_mic_last_progress_tick = 0;
static const char *s_mic_last_stage = "idle";
static TaskHandle_t s_contact_task = NULL;
static volatile bool s_contact_running = false;
static volatile int s_contact_last_seconds = 0;
static volatile esp_err_t s_contact_last_result = ESP_OK;
static volatile TickType_t s_contact_last_progress_tick = 0;

static void s_append_event_log(const char *fmt, ...)
{
    FILE *f = fopen("/sdcard/rec_event.txt", "a");
    if (f == NULL) {
        return;
    }
    va_list args;
    va_start(args, fmt);
    vfprintf(f, fmt, args);
    va_end(args);
    fputc('\n', f);
    fflush(f);
    fsync(fileno(f));
    fclose(f);
}

// Applies software gain with clipping.
static int32_t s_apply_gain(int32_t sample)
{
#if MIC_GAIN_MULT > 1
    int64_t v = (int64_t)sample * MIC_GAIN_MULT;
    if (v > INT32_MAX) {
        return INT32_MAX;
    }
    if (v < INT32_MIN) {
        return INT32_MIN;
    }
    return (int32_t)v;
#else
    return sample;
#endif
}

// Logs an info message (and optionally OLED if enabled).
static void s_log_info(const char *fmt, ...)
{
    char buf[64];
    va_list args;
    va_start(args, fmt);
    vsnprintf(buf, sizeof(buf), fmt, args);
    va_end(args);
    ESP_LOGI(TAG, "%s", buf);
    //oled_ssd1306_display_text(buf);
}

// Logs an error message (and shows it on OLED).
static void s_log_error(const char *fmt, ...)
{
    char buf[64];
    va_list args;
    va_start(args, fmt);
    vsnprintf(buf, sizeof(buf), fmt, args);
    va_end(args);
    ESP_LOGE(TAG, "%s", buf);
    oled_ssd1306_display_text(buf);
}

static void s_mic_task_entry(void *arg)
{
    mic_capture_args_t *args = (mic_capture_args_t *)arg;
    int captured_seconds = 0;
    esp_err_t result = mic_capture_to_file(args->path, args->seconds, &captured_seconds);
    s_mic_last_seconds = captured_seconds;
    s_mic_last_result = result;
    s_mic_running = false;
    s_mic_task = NULL;
    free(args);
    vTaskDelete(NULL);
}

static void s_contact_task_entry(void *arg)
{
    mic_capture_args_t *args = (mic_capture_args_t *)arg;
    int captured_seconds = 0;
    esp_err_t result = mic_capture_contact_to_file(args->path, args->seconds, &captured_seconds);
    s_contact_last_seconds = captured_seconds;
    s_contact_last_result = result;
    s_contact_running = false;
    s_contact_task = NULL;
    free(args);
    vTaskDelete(NULL);
}

const char *mic_capture_last_stage(void)
{
    return s_mic_last_stage;
}

TickType_t mic_capture_last_progress_tick(void)
{
    return s_mic_last_progress_tick;
}

TickType_t mic_capture_contact_last_progress_tick(void)
{
    return s_contact_last_progress_tick;
}

esp_err_t mic_capture_start(const char *path, int seconds)
{
    if (s_mic_running) {
        return ESP_ERR_INVALID_STATE;
    }

    mic_capture_args_t *args = (mic_capture_args_t *)calloc(1, sizeof(*args));
    if (args == NULL) {
        return ESP_ERR_NO_MEM;
    }

    strlcpy(args->path, path, sizeof(args->path));
    args->seconds = seconds;
    s_mic_running = true;
    s_mic_last_seconds = 0;
    s_mic_last_result = ESP_OK;
    s_mic_last_progress_tick = xTaskGetTickCount();

    if (xTaskCreate(s_mic_task_entry, "mic_record", 4096, args, 5, &s_mic_task) != pdPASS) {
        s_mic_running = false;
        free(args);
        return ESP_FAIL;
    }
    return ESP_OK;
}

esp_err_t mic_capture_contact_start(const char *path, int seconds)
{
    if (s_contact_running) {
        return ESP_ERR_INVALID_STATE;
    }

    mic_capture_args_t *args = (mic_capture_args_t *)calloc(1, sizeof(*args));
    if (args == NULL) {
        return ESP_ERR_NO_MEM;
    }

    strlcpy(args->path, path, sizeof(args->path));
    args->seconds = seconds;
    s_contact_running = true;
    s_contact_last_seconds = 0;
    s_contact_last_result = ESP_OK;
    s_contact_last_progress_tick = xTaskGetTickCount();

    if (xTaskCreate(s_contact_task_entry, "contact_record", 6144, args, 5, &s_contact_task) != pdPASS) {
        s_contact_running = false;
        free(args);
        return ESP_FAIL;
    }
    return ESP_OK;
}

bool mic_capture_is_running(void)
{
    return s_mic_running;
}

bool mic_capture_contact_is_running(void)
{
    return s_contact_running;
}

esp_err_t mic_capture_wait(int *out_seconds, TickType_t timeout)
{
    const TickType_t start = xTaskGetTickCount();
    while (s_mic_running) {
        if (timeout != portMAX_DELAY && (xTaskGetTickCount() - start) > timeout) {
            return ESP_ERR_TIMEOUT;
        }
        vTaskDelay(pdMS_TO_TICKS(50));
    }
    if (out_seconds != NULL) {
        *out_seconds = s_mic_last_seconds;
    }
    return s_mic_last_result;
}

esp_err_t mic_capture_contact_wait(int *out_seconds, TickType_t timeout)
{
    const TickType_t start = xTaskGetTickCount();
    while (s_contact_running) {
        if (timeout != portMAX_DELAY && (xTaskGetTickCount() - start) > timeout) {
            return ESP_ERR_TIMEOUT;
        }
        vTaskDelay(pdMS_TO_TICKS(50));
    }
    if (out_seconds != NULL) {
        *out_seconds = s_contact_last_seconds;
    }
    return s_contact_last_result;
}

// Writes a 16-bit little-endian value to a file.
static void s_write_le16(FILE *f, uint16_t value)
{
    uint8_t b[2] = {value & 0xff, (value >> 8) & 0xff};
    fwrite(b, 1, sizeof(b), f);
}
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

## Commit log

2026-01-25 Added camera module, no functionality yet
2026-02-01 split camera/OLED I2C, stabilize OV2640 MJPEG capture, and harden SD/video file handling
    [button.c, camera_ov2640.c, i2c_bus.c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]
2026-02-02 Moved camera-related code into camera_ov2640.c, updated mic capture to its oown task, and added SD card mounting OLED error
2026-02-02 Updated README.md to include camera and cleaned it up
2026-03-06 received feedback from Andy + others and revised board
    [Contact Mic Board.kicad_pcb, Contact Mic Board.kicad_sch, Main Board.kicad_pcb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]
2026-03-10 submitted for manufacturinng. Flipped contact mic connections on main board to be aligned with contact mic board
    [Contact Mic Board.kicad_pcb, Main Board.kicad_pcb, Main Board.kicad_sch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]
2026-03-11 fixed power button and via proximity to pad on main board
    [Contact Mic Board.kicad_pcb, Main Board.kicad_pcb, Main Board.kicad_sch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]
2026-04-02 Add custom board pin remap and bring-up logging
2026-04-02 identified pin issue, buzzer conflicted with oled. camera vsync and pclck were bridged. Fixed both hardware bugs.
    [button.c, mic_capture.c, oled_ssd1306.c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]
2026-04-02 Remap custom board GPIOs for SD, camera, mic, OLED, and button; remove buzzer code; disable BLE duplicate filtering
2026-04-08 began board migration to newer integrated camera 24 pin connector, NOT FINISHED
    [Main Board.kicad_pcb, Main Board.kicad_sch]
2026-04-14 added OLED failure handling, added event/error logs to txt files(not working as expected). added boot reset-cause display on oled. Disabled BLE scanning for testing, and that appears to be what stopp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
    [button.c, camera_ov2640.c, mic_capture.c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]
2026-04-14 Re-enable BLE trigger scanning and reduce passive scan duty cycle from 100% (10 ms every 10 ms) to 25% (10 ms every 40 ms), while keeping duplicate filtering off and preserving the custom UUID trigge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
2026-04-17 Update Hardware folder backups for contact mic and main board
2026-04-17 added ov2640 footprint
    [Main Board.kicad_sch, OV2640.step]
2026-04-18 found the schematics
    [OV2640.step]
2026-04-18 ov2640 footprints
    [Main Board.kicad_sch]
2026-04-20 finished ov2640 schematic
    [Main Board.kicad_sch]
2026-04-20 camera pcb
    [Main Board.kicad_pcb, Main Board.kicad_sch]
2026-04-20 Add contact mic debug mode that scans the shared I2C bus, retries ES8388 codec initialization until it comes up, shows retry/status updates on the OLED, and records a left-only mono WAV test capture 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
2026-04-22 Integrate contact mic into recording flow and initialize ES8388 once at boot
2026-04-26 finished camera pcb
    [Main Board-B_Cu.gbl, Main Board-B_Mask.gbs, Main Board-B_Paste.gbp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]
2026-04-30 reviewed kevin's layout, changed boot reset buttons and updated layout
    [Main Board.kicad_pcb, Main Board.kicad_sch]
2026-05-01 Fix contact timestamp naming and lower camera FPS for stability
    [camera_ov2640.c, sd_card_example_main.c]
2026-05-06 Improve recording stop diagnostics and add contact codec boot settle delay
    Show explicit OLED stop reasons instead of silently falling back to Ready, including BLE stop, button stop, mic read/write/flush/seek failures, and contact mic failure stages.
    Add standard-mic stage tracking and check write/flush/seek failures so SD card write problems surface as recorder errors instead of being ignored.
    Add a 500 ms boot-settle delay before the first ES8388 initialization attempt while keeping the existing retry logic, so codec power and bias nodes have time to settle before the first register writes.
    [button.c, mic_capture.c, sd_card_example_main.c]
2026-05-07 fixed data 0 and data 1 no connect issue, data pins for camera start at D2-D9
    [Main Board.kicad_pcb, Main Board.kicad_sch]
2026-05-08 fixed drc issues
    [Main Board.kicad_pcb]
2026-05-11 Pull hardware updates from codex temp branch
    Bring the main board hardware changes from origin/codex-temp-main-hardware-push onto main while excluding transient KiCad autosave and lock files.
    [Main Board.kicad_pcb, Main Board.kicad_sch, Main Board.stl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]
2026-05-12 submitted for manufacturing
    [Main Board.kicad_pcb, Main Board.kicad_sch, bom.csv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]
2026-05-13 Mitigate contact-audio stalls and stop runaway camera recording
    Diagnosis: long recordings were showing a pattern where both audio files stopped well before the video file, followed later by INT_WDT resets. That pointed to an audio-side stall rather than a clean stop or simple brownout: the main loop waited indefinitely on mic tasks while button_is_recording() stayed true, so the camera task kept recording independently.
    Mitigations in this commit: increase audio autosave interval from 3 s to 10 s, stagger contact autosave by 5 s so the two WAV header updates do not collide, remove periodic fsync() from mid-record autosaves while keeping final flush+fsync at close, add audio progress heartb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
    [camera_ov2640.c, mic_capture.c, sd_card_example_main.c]
2026-05-13 Add OLED error log if there's no SD card
    [sd_card_example_main.c]
2026-05-20 Add segmented auto-restart for stalled recordings
    Detect mic and contact-mic stalls in the existing triple-task recorder and recover by rolling the session into a new segment instead of ending the overall recording. The restart path now preserves cumulative elapsed time on the OLED, shows the stalled subsystem before restarting, and keeps all three streams aligned by restarting standard mic, contact mic, and video together.
    Implement a strict 8-character filename stem for segmented sessions: DDHHMMXY when a BLE timestamp is available, and a zero-padded 6-digit session index plus type and segment when it is not. X selects the stream type (S, C, or V) and Y advances from A upward for each aut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
    [button.c, sd_card_example_main.c]
